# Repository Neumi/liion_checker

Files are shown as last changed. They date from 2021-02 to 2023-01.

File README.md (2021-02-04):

# 18650 Battery Checker 
A 18650 Li-Ion battery checker and charger that can be loaded and unloaded by a robotic gripper. Up to 127 devices can be connected on one i2c bus to exchange test results with a master that is connected to a SPS/Arduino/Raspberry Pi.

## Main features:
 - TP4056 charger up to 1A charge current
 - discharging with a programmable constant current sink
 - i2c interconnectivity to other chargers and a master
 - 18650 cells can be placed/removed by a robotic gripper

## Images

### Sorting Machine
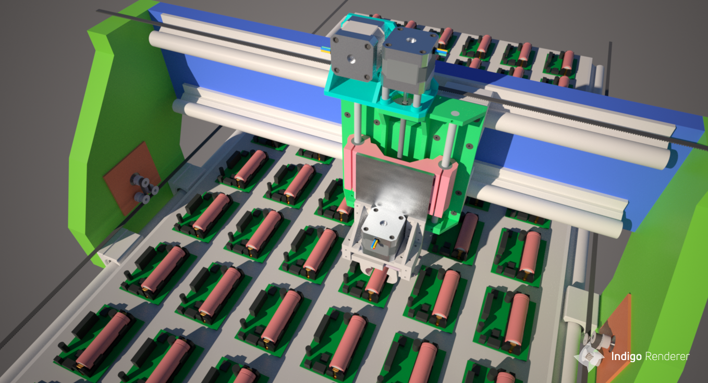
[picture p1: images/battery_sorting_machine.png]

PCB rendering
### Layout and Board
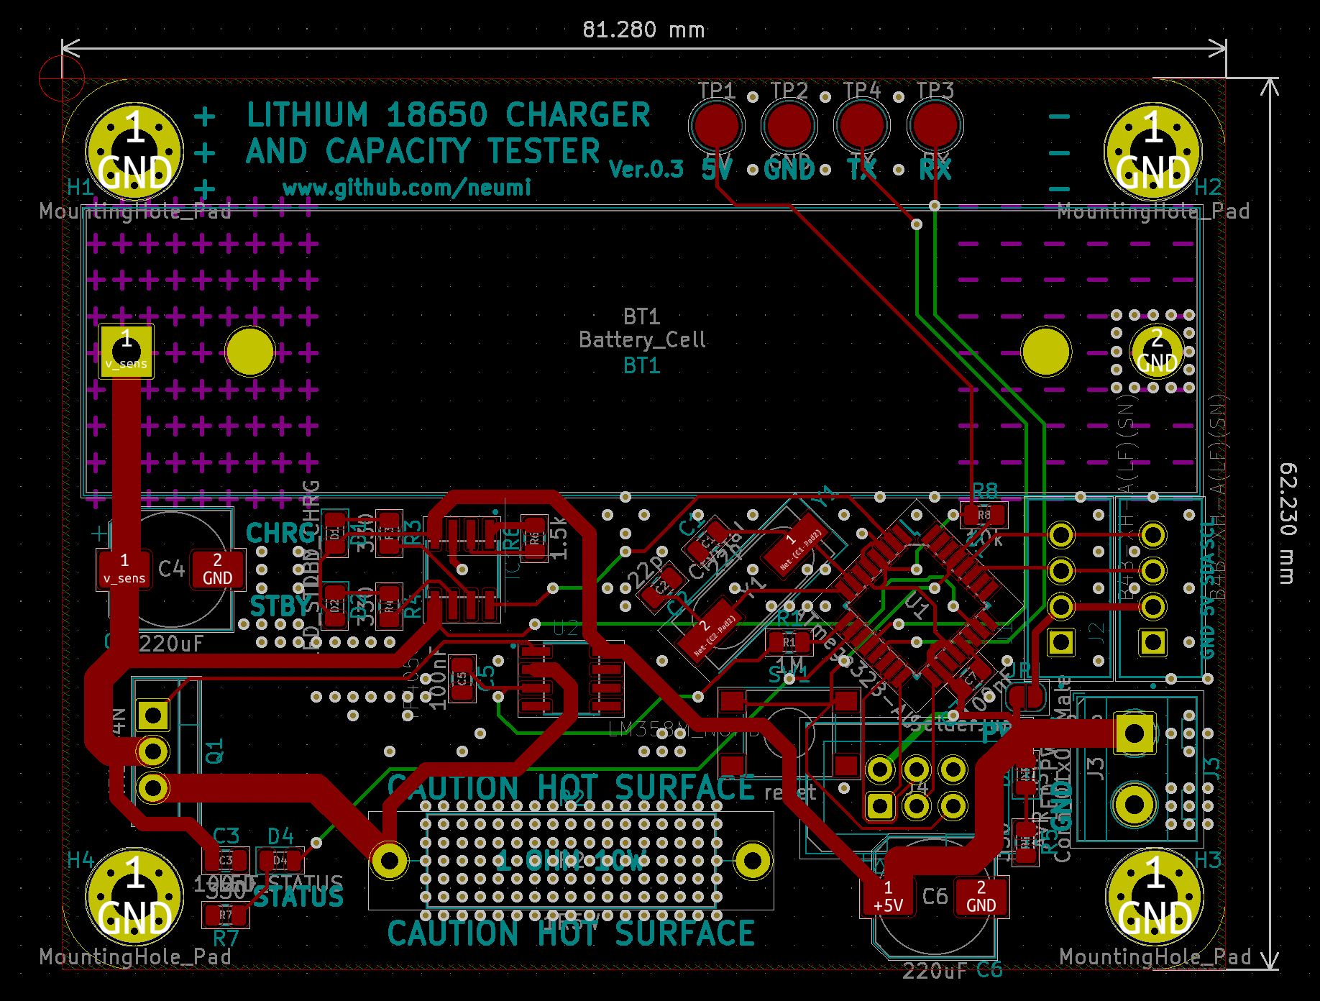
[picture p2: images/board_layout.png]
PCB layout

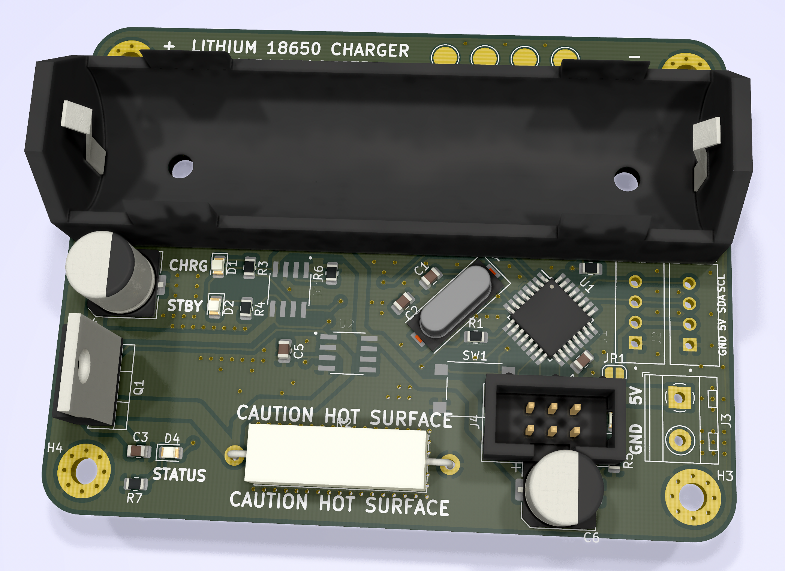
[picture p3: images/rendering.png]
PCB rendering


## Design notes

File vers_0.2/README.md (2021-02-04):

# Version 0.2
Version 0.2 is a four battery approach with only one microcontroller that manages charging/discharging/measurements for all four cells at once.

Board needs layout. Schematic is done.

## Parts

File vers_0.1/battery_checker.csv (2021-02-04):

Id | Designator | Package | Quantity | Designation | Supplier and ref
1 | BT1 | BatteryHolder_MPD_BH-18650-PC2 | 1 | Battery_Cell
2 | C1,C2 | C_0805_2012Metric | 2 | 22p
3 | C3,C5,C7 | C_0805_2012Metric | 3 | 100nF
4 | C4,C6 | CP_Elec_8x10 | 2 | 220uF
5 | D1 | LED_0805_2012Metric | 1 | LED_CHRG
6 | D2 | LED_0805_2012Metric | 1 | LED_STDBY
7 | D3 | LED_0805_2012Metric | 1 | LED_PWR
8 | IC1 | SOIC127P599X175-8N | 1 | TP4056
9 | J1,J2 | JST_B4B-XH-A(LF)(SN) | 2 | B4B-XH-A(LF)(SN)
10 | Q1 | TO-263-2 | 1 | IRLZ44N
11 | R1 | R_0805_2012Metric | 1 | 1M
12 | R2 | R_Axial_Power_L20.0mm_W6.4mm_P25.40mm | 1 | 1R5W
13 | R3,R4,R5,R7 | R_0805_2012Metric | 4 | 330
14 | R6 | R_0805_2012Metric | 1 | 1.5k
15 | SW1 | SW_Push_1P1T_NO_CK_KSC7xxJ | 1 | reset
16 | U1 | TQFP-32_7x7mm_P0.8mm | 1 | ATmega328-AU
17 | U2 | SOIC127P599X175-8N | 1 | LM358M_NOPB
18 | Y1 | Crystal_SMD_HC49-SD | 1 | Crystal
19 | J3 | TerminalBlock_MetzConnect_Type094_RT03502HBLU_1x02_P5.00mm_Horizontal | 1 | Conn_01x02_Male
20 | H1,H2,H3,H4 | MountingHole_3.2mm_M3_Pad_Via | 4 | MountingHole_Pad
21 | JP1 | SolderJumper-2_P1.3mm_Open_RoundedPad1.0x1.5mm | 1 | SolderJumper_2_Open
22 | D4 | LED_0805_2012Metric | 1 | LED_STATUS
23 | J4 | IDC-Header_2x03_P2.54mm_Vertical | 1 | AVR-ISP-6
24 | R8 | R_0805_2012Metric | 1 | 10k
25 | TP1 | TestPoint_Pad_D3.0mm | 1 | 5V
26 | TP2 | TestPoint_Pad_D3.0mm | 1 | GND
27 | TP3 | TestPoint_Pad_D3.0mm | 1 | RX
28 | TP4 | TestPoint_Pad_D3.0mm | 1 | TX

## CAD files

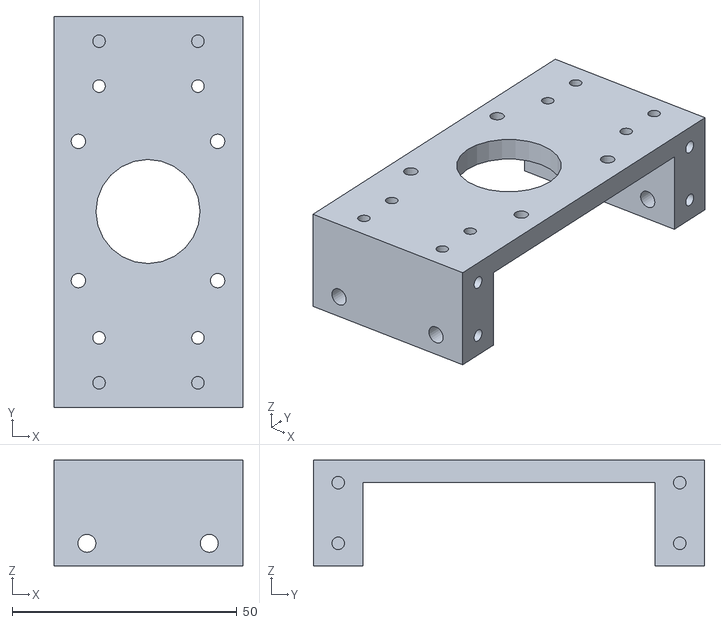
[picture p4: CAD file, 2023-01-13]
cad/stl/main_body.stl
42.0 x 87.0 x 23.5

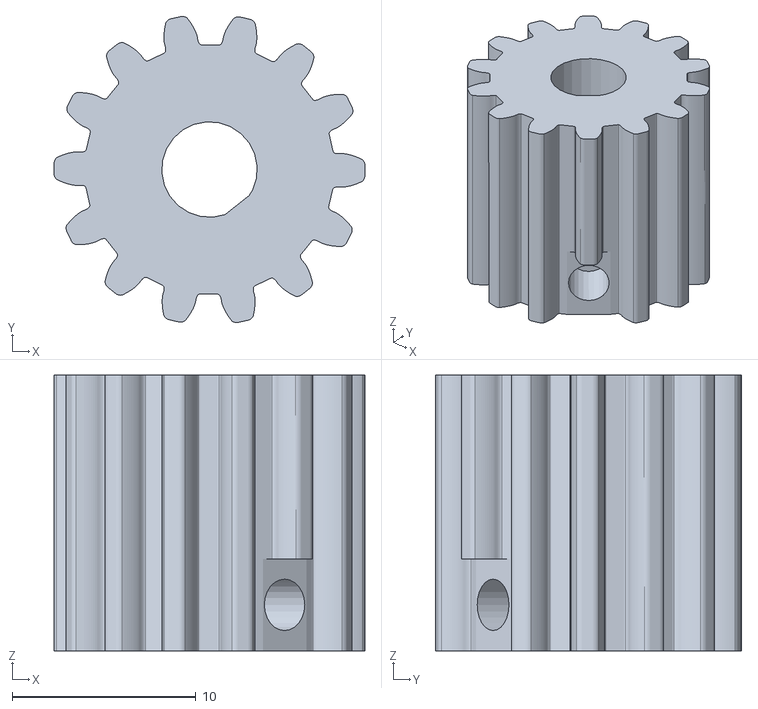
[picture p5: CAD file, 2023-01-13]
cad/stl/gear.stl
16.9 x 16.7 x 15.0

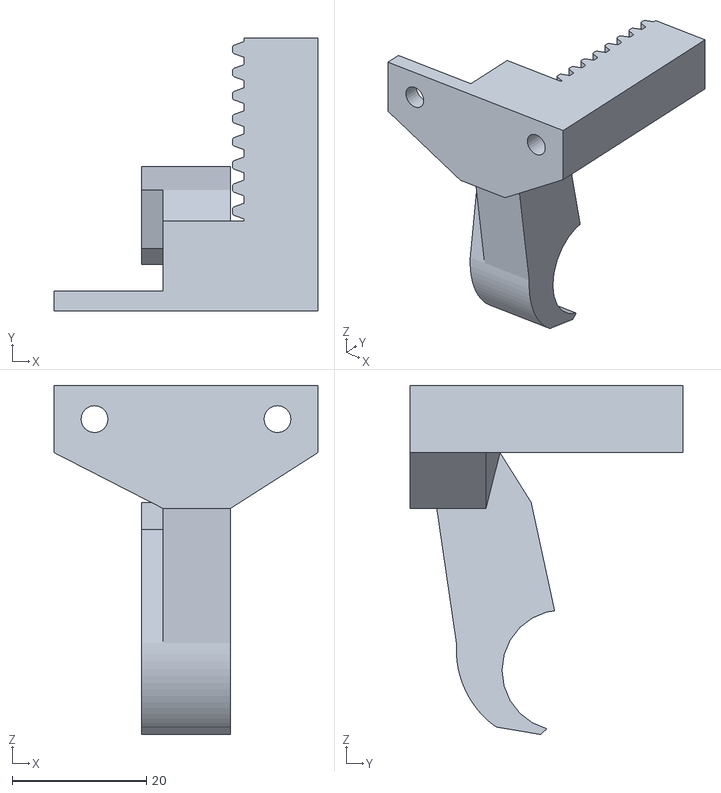
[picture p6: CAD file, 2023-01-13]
cad/stl/gripper_half.stl
39.2 x 40.7 x 51.9

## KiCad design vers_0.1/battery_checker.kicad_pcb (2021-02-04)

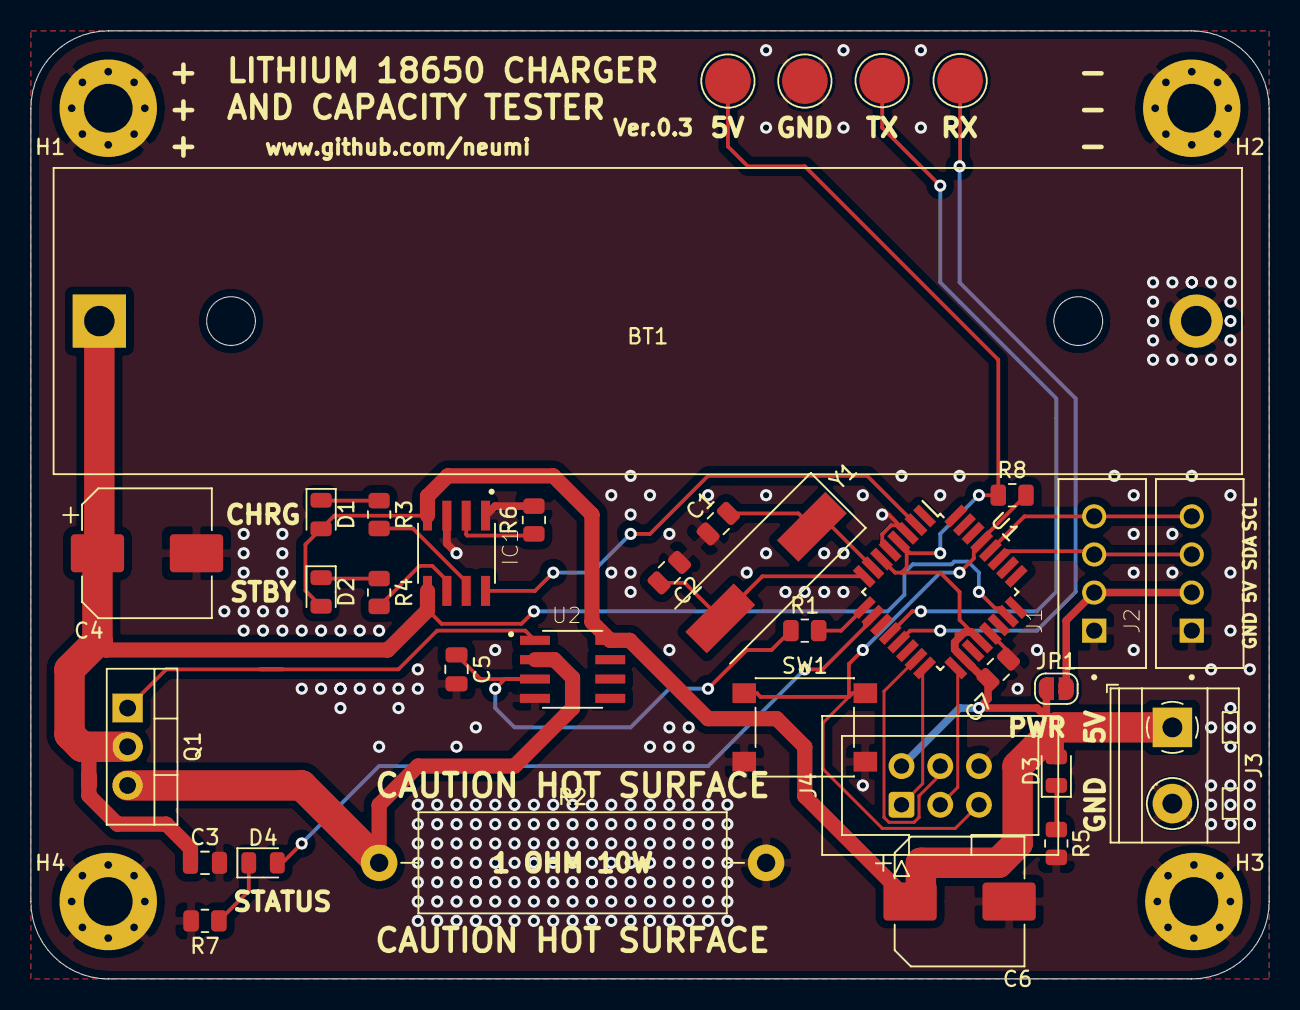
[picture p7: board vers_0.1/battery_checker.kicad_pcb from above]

Board: 2 copper layers, 81.3 x 62.2 mm, 39 parts (0 on the bottom side), 27 nets.

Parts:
BT1: Battery_Cell; BatteryHolder_MPD_BH-18650-PC2
C1, C2: 22p; C_0805_2012Metric
C3, C5, C7: 100nF; C_0805_2012Metric
C4, C6: 220uF; CP_Elec_8x10
D1: LED_CHRG; LED_0805_2012Metric
D2: LED_STDBY; LED_0805_2012Metric
D3: LED_PWR; LED_0805_2012Metric
D4: LED_STATUS; LED_0805_2012Metric
H1, H2, H3, H4: MountingHole_Pad; MountingHole_3.2mm_M3_Pad_Via
IC1: TP4056; SOIC127P599X175-8N
J1, J2: B4B-XH-A(LF)(SN); JST_B4B-XH-A(LF)(SN)
J3: Conn_01x02_Male; TerminalBlock_MetzConnect_Type094_RT03502HBLU_1x02_P5.00mm_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
J4: AVR-ISP-6; IDC-Header_2x03_P2.54mm_Vertical
JP1: SolderJumper_2_Open; SolderJumper-2_P1.3mm_Open_RoundedPad1.0x1.5mm
Q1: IRLZ44N; TO-220-3_Vertical
R1: 1M; R_0805_2012Metric
R2: 1R5W; R_Axial_Power_L20.0mm_W6.4mm_P25.40mm
R3, R4, R5, R7: 330; R_0805_2012Metric
R6: 1.5k; R_0805_2012Metric
R8: 10k; R_0805_2012Metric
SW1: reset; SW_Push_1P1T_NO_6x6mm_H9.5mm
TP1: 5V; TestPoint_Pad_D3.0mm
TP2: GND; TestPoint_Pad_D3.0mm
TP3: RX; TestPoint_Pad_D3.0mm
TP4: TX; TestPoint_Pad_D3.0mm
U1: ATmega328-AU; TQFP-32_7x7mm_P0.8mm
U2: LM358M_NOPB; SOIC127P599X175-8N
Y1: Crystal; Crystal_SMD_HC49-SD

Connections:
+5V: C6.1, C7.1, D1.2, D2.2, D3.2, IC1.4, J3.1, J4.2, JP1.1, R8.1, TP1.1, U1.4, U1.6, U1.18, U1.20, U2.8
CHRG_enable: IC1.8, U1.2
GND: BT1.2, C1.1, C2.1, C3.2, C4.2, C5.2, C6.2, C7.2, H1.1, H2.1, H3.1, H4.1, IC1.1, IC1.3, J1.1, J2.1, J3.2, J4.6, R2.2, R5.2, R6.2, R7.2, SW1.2, TP2.1, U1.3, U1.5, U1.21, U2.4
LED_STATUS: D4.2, U1.10
MISO: J4.1, U1.16
MOSI: J4.4, U1.15
unnamed: C1.2, U1.7, Y1.1
unnamed: C2.2, U1.8, Y1.2
unnamed: C5.1, R1.1, U2.3
unnamed: D1.1, R3.1
unnamed: D2.1, R4.1
unnamed: D3.1, R5.1
unnamed: D4.1, R7.1
unnamed: IC1.2, R6.1
unnamed: IC1.6, R4.2
unnamed: IC1.7, R3.2
unnamed: J1.2, J2.2, JP1.2
unnamed: Q1.1, U2.1
unnamed: Q1.3, R2.1, U2.2
PWM: R1.2, U1.9
RST: J4.5, R8.2, SW1.1, U1.29
RX: TP3.1, U1.13
SCK: J4.3, U1.17
SCL: J1.4, J2.4, U1.28
SDA: J1.3, J2.3, U1.27
TX: TP4.1, U1.12
v_sens: BT1.1, C3.1, C4.1, IC1.5, Q1.2, U1.23

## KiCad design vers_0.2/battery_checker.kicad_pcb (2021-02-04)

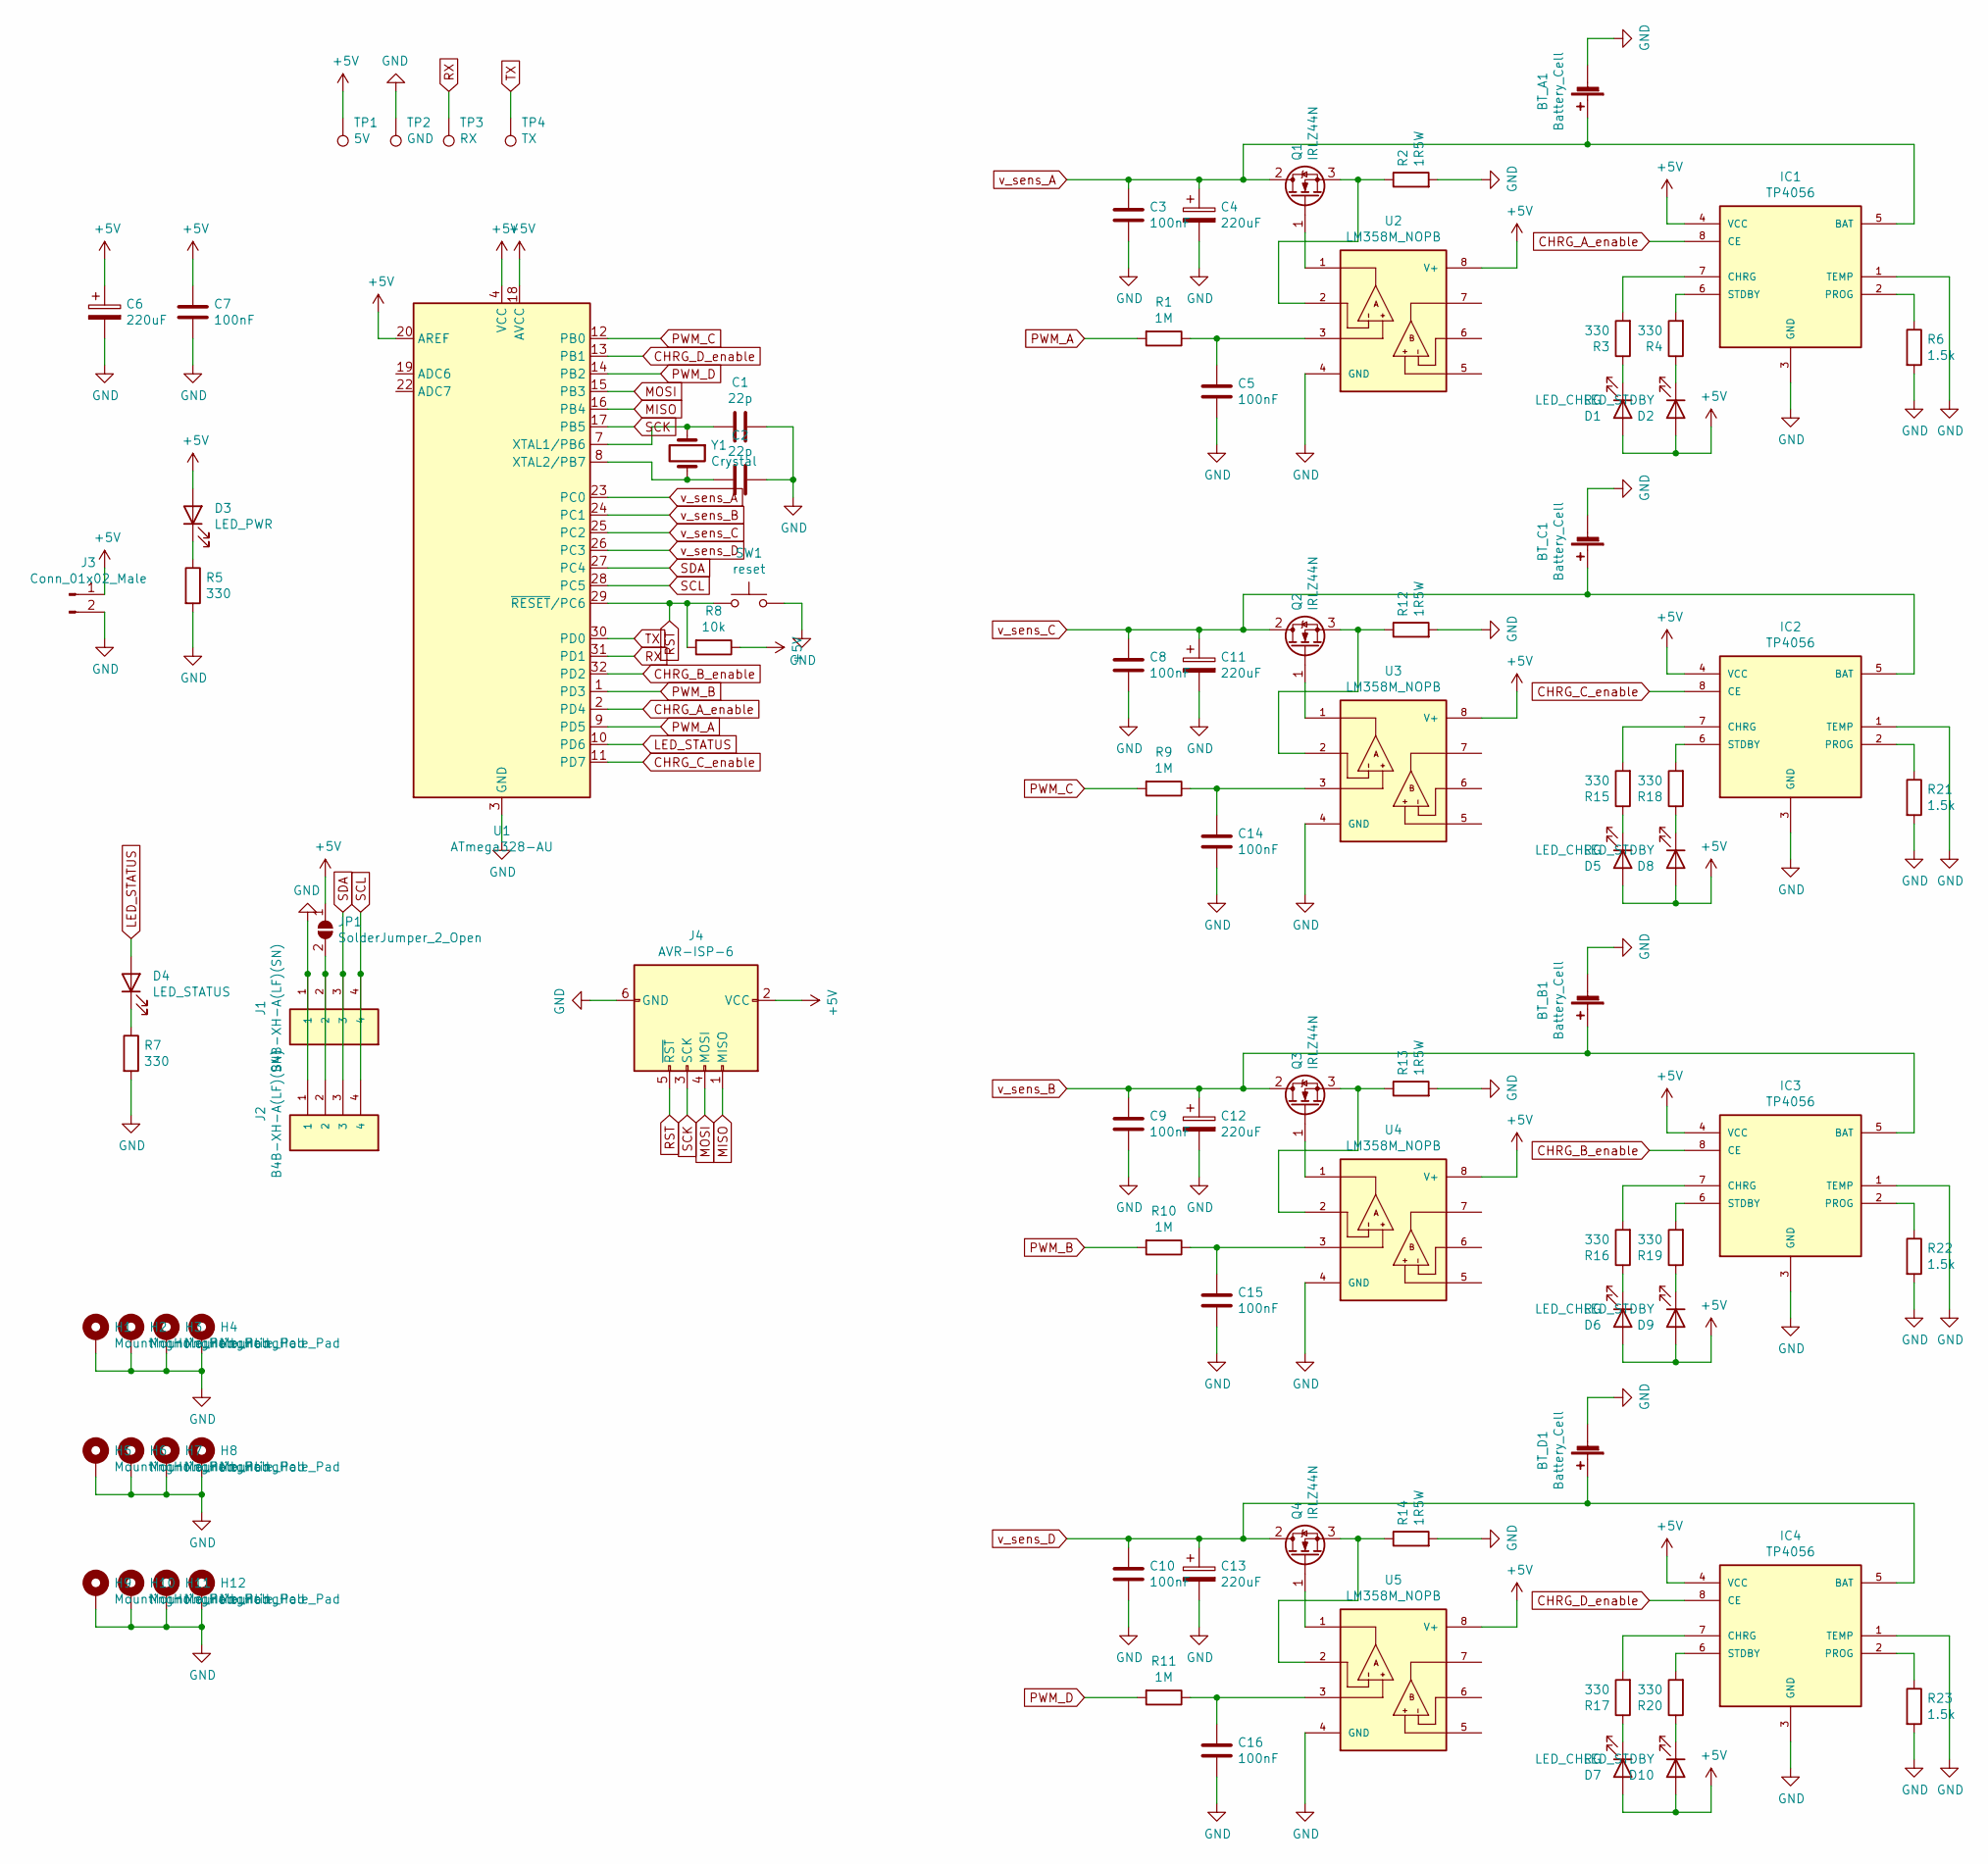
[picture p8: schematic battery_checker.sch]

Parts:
BT_A1: Battery_Cell; BatteryHolder_MPD_BH-18650-PC2
BT_B1: Battery_Cell; BatteryHolder_MPD_BH-18650-PC2
BT_C1: Battery_Cell; BatteryHolder_MPD_BH-18650-PC2
BT_D1: Battery_Cell; BatteryHolder_MPD_BH-18650-PC2
C1, C2: 22p; C_0805_2012Metric
C3, C5, C7, C8, C9, C10, C14, C15, C16: 100nF; C_0805_2012Metric
C4, C6, C11, C12, C13: 220uF; CP_Elec_8x10
D1, D5, D6, D7: LED_CHRG; LED_0805_2012Metric
D2, D8, D9, D10: LED_STDBY; LED_0805_2012Metric
D3: LED_PWR; LED_0805_2012Metric
D4: LED_STATUS; LED_0805_2012Metric
H1, H2, H3, H4, H5, H6, H7, H8, H9, H10, H11, H12: MountingHole_Pad; MountingHole_3.2mm_M3_Pad_Via
IC1, IC2, IC3, IC4: TP4056; SOIC127P599X175-8N
J1, J2: B4B-XH-A(LF)(SN); JST_B4B-XH-A(LF)(SN); PARTREV NA
J3: Conn_01x02_Male; TerminalBlock_MetzConnect_Type094_RT03502HBLU_1x02_P5.00mm_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
J4: AVR-ISP-6; IDC-Header_2x03_P2.54mm_Vertical
JP1: SolderJumper_2_Open; SolderJumper-2_P1.3mm_Open_RoundedPad1.0x1.5mm
Q1, Q2, Q3, Q4: IRLZ44N; TO-220-3_Vertical
R1, R9, R10, R11: 1M; R_0805_2012Metric
R2, R12, R13, R14: 1R5W; R_Axial_Power_L20.0mm_W6.4mm_P25.40mm
R3, R4, R5, R7, R15, R16, R17, R18, R19, R20: 330; R_0805_2012Metric
R6, R21, R22, R23: 1.5k; R_0805_2012Metric
R8: 10k; R_0805_2012Metric
SW1: reset; SW_Push_1P1T_NO_6x6mm_H9.5mm
TP1: 5V; TestPoint_Pad_D3.0mm
TP2: GND; TestPoint_Pad_D3.0mm
TP3: RX; TestPoint_Pad_D3.0mm
TP4: TX; TestPoint_Pad_D3.0mm
U1: ATmega328-AU; TQFP-32_7x7mm_P0.8mm
U2, U3, U4, U5: LM358M_NOPB; SOIC127P599X175-8N
Y1: Crystal; Crystal_SMD_HC49-SD

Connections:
+5V: C6.1, C7.1, D1.2 (A), D2.2 (A), D3.2 (A), D5.2 (A), D6.2 (A), D7.2 (A), D8.2 (A), D9.2 (A), D10.2 (A), IC1.4 (VCC), IC2.4 (VCC), IC3.4 (VCC), IC4.4 (VCC), J3.1, J4.2 (VCC), JP1.1 (A), R8.1, TP1.1, U1.4 (VCC), U1.6 (VCC), U1.18 (AVCC), U1.20 (AREF), U2.8 (V+), U3.8 (V+), U4.8 (V+), U5.8 (V+)
CHRG_A_enable: IC1.8 (CE), U1.2 (PD4)
CHRG_B_enable: IC3.8 (CE), U1.32 (PD2)
CHRG_C_enable: IC2.8 (CE), U1.11 (PD7)
CHRG_D_enable: IC4.8 (CE), U1.13 (PB1)
GND: BT_A1.2 (-), BT_B1.2 (-), BT_C1.2 (-), BT_D1.2 (-), C1.1, C2.1, C3.2, C4.2, C5.2, C6.2, C7.2, C8.2, C9.2, C10.2, C11.2, C12.2, C13.2, C14.2, C15.2, C16.2, H1.1, H2.1, H3.1, H4.1, H5.1, H6.1, H7.1, H8.1, H9.1, H10.1, H11.1, H12.1, IC1.1 (TEMP), IC1.3 (GND), IC2.1 (TEMP), IC2.3 (GND), IC3.1 (TEMP), IC3.3 (GND), IC4.1 (TEMP), IC4.3 (GND), J1.1, J2.1, J3.2, J4.6 (GND), R2.2, R5.2, R6.2, R7.2, R12.2, R13.2, R14.2, R21.2, R22.2, R23.2, SW1.2, TP2.1, U1.3 (GND), U1.5 (GND), U1.21 (GND), U2.4 (GND), U3.4 (GND), U4.4 (GND), U5.4 (GND)
LED_STATUS: D4.2 (A), U1.10 (PD6)
MISO: J4.1 (MISO), U1.16 (PB4)
MOSI: J4.4 (MOSI), U1.15 (PB3)
unnamed: C1.2, U1.7 (XTAL1/PB6), Y1.1
unnamed: C2.2, U1.8 (XTAL2/PB7), Y1.2
unnamed: C5.1, R1.1, U2.3
unnamed: C14.1, R9.1, U3.3
unnamed: C15.1, R10.1, U4.3
unnamed: C16.1, R11.1, U5.3
unnamed: D1.1 (K), R3.1
unnamed: D2.1 (K), R4.1
unnamed: D3.1 (K), R5.1
unnamed: D4.1 (K), R7.1
unnamed: D5.1 (K), R15.1
unnamed: D6.1 (K), R16.1
unnamed: D7.1 (K), R17.1
unnamed: D8.1 (K), R18.1
unnamed: D9.1 (K), R19.1
unnamed: D10.1 (K), R20.1
unnamed: IC1.2 (PROG), R6.1
unnamed: IC1.6 (STDBY), R4.2
unnamed: IC1.7 (CHRG), R3.2
unnamed: IC2.2 (PROG), R21.1
unnamed: IC2.6 (STDBY), R18.2
unnamed: IC2.7 (CHRG), R15.2
unnamed: IC3.2 (PROG), R22.1
unnamed: IC3.6 (STDBY), R19.2
unnamed: IC3.7 (CHRG), R16.2
unnamed: IC4.2 (PROG), R23.1
unnamed: IC4.6 (STDBY), R20.2
unnamed: IC4.7 (CHRG), R17.2
unnamed: J1.2, J2.2, JP1.2 (B)
unnamed: Q1.1 (G), U2.1
unnamed: Q1.3 (S), R2.1, U2.2
unnamed: Q2.1 (G), U3.1
unnamed: Q2.3 (S), R12.1, U3.2
unnamed: Q3.1 (G), U4.1
unnamed: Q3.3 (S), R13.1, U4.2
unnamed: Q4.1 (G), U5.1
unnamed: Q4.3 (S), R14.1, U5.2
PWM_A: R1.2, U1.9 (PD5)
PWM_B: R10.2, U1.1 (PD3)
PWM_C: R9.2, U1.12 (PB0)
PWM_D: R11.2, U1.14 (PB2)
RST: J4.5 (~RST), R8.2, SW1.1, U1.29 (~RESET~/PC6)
RX: TP3.1, U1.31 (PD1)
SCK: J4.3 (SCK), U1.17 (PB5)
SCL: J1.4, J2.4, U1.28 (PC5)
SDA: J1.3, J2.3, U1.27 (PC4)
TX: TP4.1, U1.30 (PD0)
v_sens_A: BT_A1.1 (+), C3.1, C4.1, IC1.5 (BAT), Q1.2 (D), U1.23 (PC0)
v_sens_B: BT_B1.1 (+), C9.1, C12.1, IC3.5 (BAT), Q3.2 (D), U1.24 (PC1)
v_sens_C: BT_C1.1 (+), C8.1, C11.1, IC2.5 (BAT), Q2.2 (D), U1.25 (PC2)
v_sens_D: BT_D1.1 (+), C10.1, C13.1, IC4.5 (BAT), Q4.2 (D), U1.26 (PC3)

Board: 2 copper layers, 89 parts (0 on the bottom side), 60 nets, no tracks yet.

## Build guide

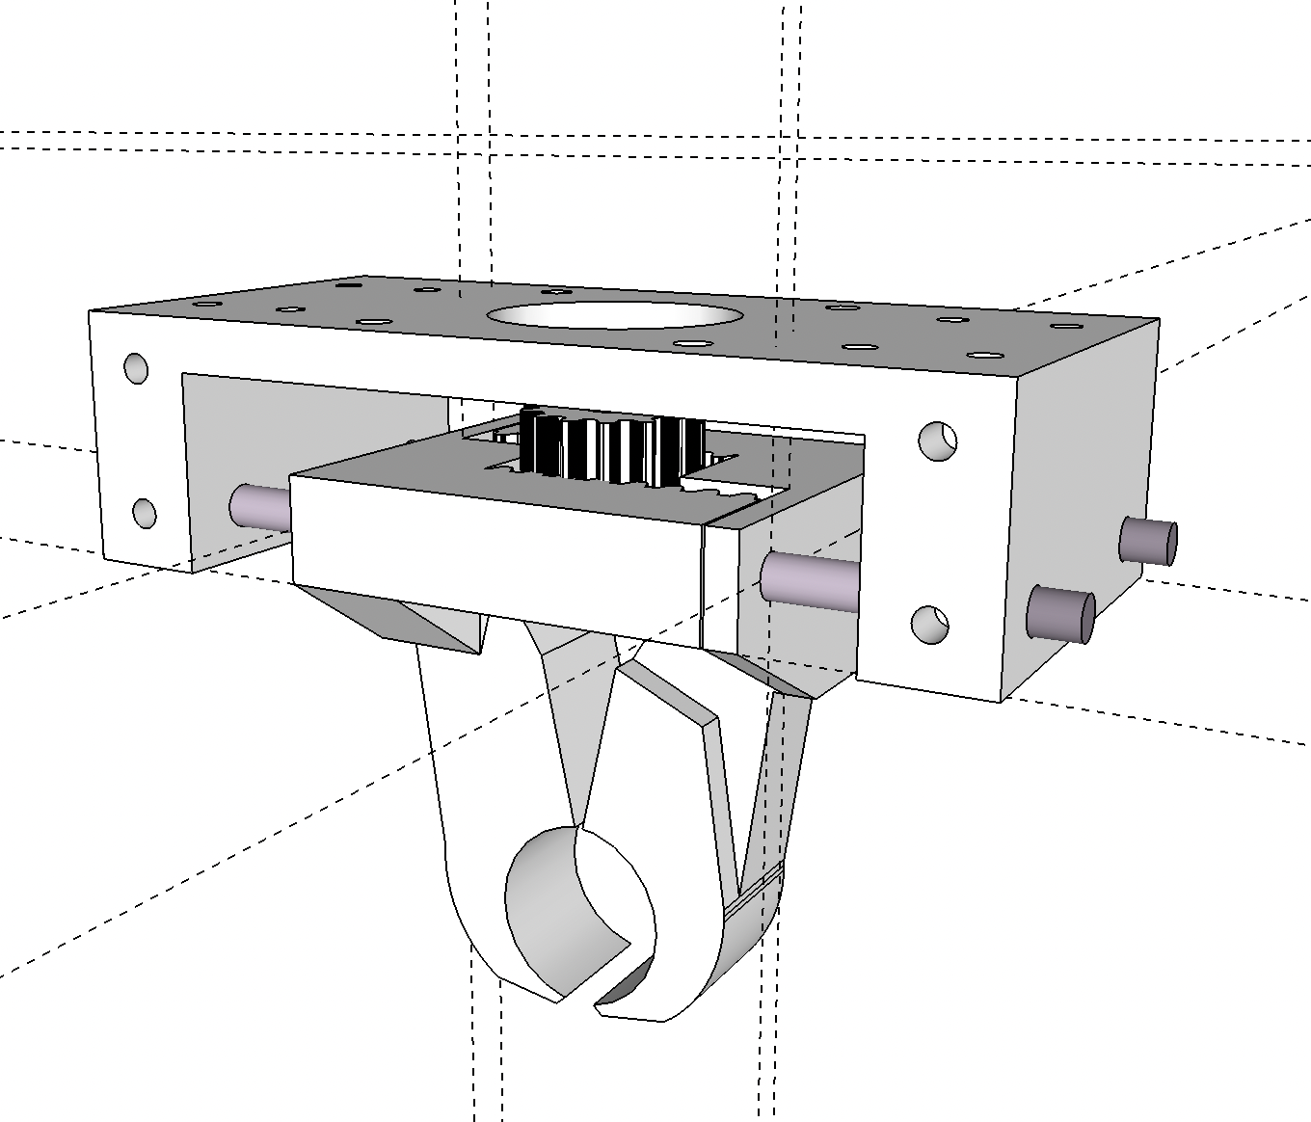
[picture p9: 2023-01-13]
cad/stl/gripper_assembly.png

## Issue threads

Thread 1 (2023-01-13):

Robotic Arm Gripper CAD Files

TGiles1998, 2023-01-13:
Hi,

Thank you so much for your work. Are the CAD files for the robot gripper available?

Many thanks,

Thomas

Neumi, 2023-01-13:
Hey Thanks for asking!
I just exported them and will upload them in the next few minutes. :)

Neumi, 2023-01-13:
closed
relates https://github.com/Neumi/liion_checker/commit/1741b37f245a0d8a992f4f4c5b05e0aa9a31439e

TGiles1998, 2023-01-13:
Is it possible to have step files as well? Many thanks,

Thomas

Neumi, 2023-01-16:
It's an older project and was designed in SketchUp. Sorry :/

Closed 2023-01-13.

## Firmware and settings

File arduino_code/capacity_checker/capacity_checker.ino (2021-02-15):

#include <SoftwareSerial.h>

SoftwareSerial mySerial(A4, A5);


int led = 6;
int load_pwm_pin = 5;
int chrge_enable_pin = 4;
int volt_detect_pin = A0;

void setup() {
  mySerial.begin(9600);
  pinMode(led, OUTPUT);
  pinMode(chrge_enable_pin, OUTPUT);
  pinMode(load_pwm_pin, OUTPUT);

  digitalWrite(chrge_enable_pin, LOW);
  analogWrite(load_pwm_pin, 0);
}

void loop() {
  delay(1000);
  dischargeUntilEmpty();
}

void dischargeUntilEmpty() {
  int voltage = checkVoltage();
  mySerial.println(voltage);
  if (voltage > 3200) {
    dischargeOn();
  } else {
    dischargeOff();
  }
}


void dischargeOn() {
  // mySerial.println("discharging ON");
  /* 10 = 222
     15 = 320
     20 = 426
     22 = 474
     23 = 495
     24 = 516
     25 = 530ma
     40 = 830ma
  */
  analogWrite(load_pwm_pin, 23);
  digitalWrite(led, HIGH);
  delay(10);
}

void dischargeOff() {
  // mySerial.println("discharging OFF");
  analogWrite(load_pwm_pin, 0);
  digitalWrite(led, LOW);
  delay(10);
}

int checkVoltage() {
  int analog = analogRead(volt_detect_pin);
  int voltage = map(analog, 0, 1023, 0, 5000);
  return voltage;
}

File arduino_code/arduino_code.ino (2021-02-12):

int led = 6;
int load_pwm_pin = 5;
int chrge_enable_pin = 4;
int volt_detect_pin = A0;
// the setup function runs once when you press reset or power the board
void setup() {
  // initialize digital pin LED_BUILTIN as an output.
  pinMode(led, OUTPUT);
  pinMode(chrge_enable_pin, OUTPUT);
  pinMode(load_pwm_pin, OUTPUT);

  digitalWrite(chrge_enable_pin, LOW);
  analogWrite(load_pwm_pin, 0);
}

// the loop function runs over and over again forever
void loop() {
  dischargeOff();

  if(checkVoltage() > 3880) {
    digitalWrite(led, HIGH);
  }
  else {
    digitalWrite(led, LOW);
  }
  
  chargeOn();
  delay(4000);
  chargeOff();
  delay(4000);
}


void chargeOff() {
  digitalWrite(chrge_enable_pin, LOW);
  delay(50);
}
void chargeOn() {
  digitalWrite(chrge_enable_pin, HIGH);
  delay(50);
}

void dischargeOn() {
  analogWrite(load_pwm_pin, 255);
  delay(50);
}

void dischargeOff() {
  analogWrite(load_pwm_pin, 0);
  delay(50);
}

int checkVoltage() {
  int analog = analogRead(volt_detect_pin);
  int voltage = map(analog, 0,1023, 0, 5000);
  return voltage;
}

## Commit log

2021-02-04 initial commit for v1 and v2
    [battery_checker-B_Cu.gbr, battery_checker-B_Mask.gbr, battery_checker-B_Paste.gbr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]
2021-02-04 added readme for versions
    [battery_checker-B_Cu.gbr, battery_checker-B_Mask.gbr, battery_checker-B_Paste.gbr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]
2021-02-15 added capcity checker arduino code
2023-01-13 added gripper STL files
    [gear.stl, gripper_half.stl, main_body.stl]
2023-01-13 added image of gripper assebly
